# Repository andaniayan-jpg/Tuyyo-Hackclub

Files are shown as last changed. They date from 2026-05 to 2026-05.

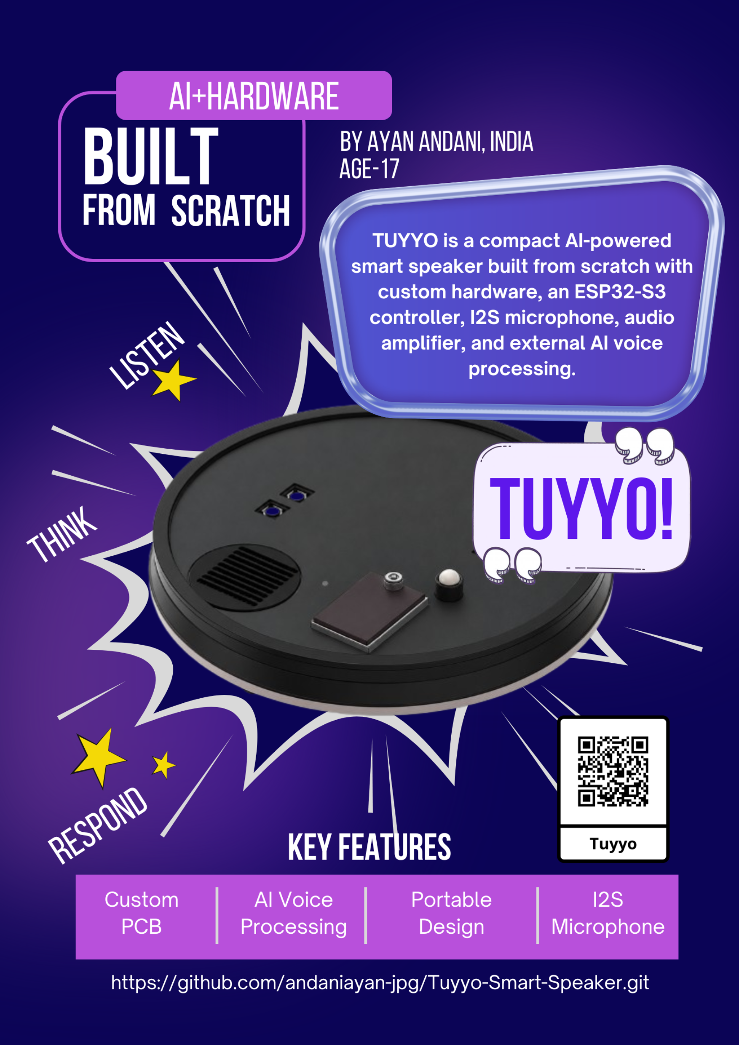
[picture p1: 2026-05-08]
ZINE PAGE .png

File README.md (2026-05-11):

# Tuyyo-Smart-Speaker

**TUYO is a compact, AI-powered voice assistant speaker that was designed and built completely from scratch. It combines custom embedded hardware with modern AI to create a portable assistant that can listen, process speech, and respond in real time.**

imresizer-trical p (1)

## Build Instructions

1. Download or clone this repository.
2. Open the KiCad project from the `PCB/` folder.
3. Review the schematic and PCB layout.
4. Generate or use the included Gerber files for PCB manufacturing.
5. Order the components listed in `BOM.csv`.
6. Assemble the PCB by soldering the ESP32-S3, microphone, amplifier, USB-C, charger, regulator, resistors, capacitors, LED, buttons, and connectors.
7. Place the assembled PCB inside the 3D printed enclosure.
8. Upload the firmware from `Firmware/tuyo_firmware.ino`.
9. Connect the external AI processing system for speech-to-text, AI response generation, and text-to-speech.
10. Power the device using USB-C or a LiPo battery.

## PCB and Schematic

The PCB was designed in KiCad. The `PCB/` folder includes the schematic, PCB layout, and manufacturing files.

## Firmware and AI Integration

The ESP32-S3 firmware initializes Wi-Fi, the I2S microphone, I2S amplifier, buttons, and status output. The ESP32 does not run the full AI model locally. It captures audio and is intended to send it to an external AI system, which handles speech-to-text, response generation, and text-to-speech playback.

# How to use it
-Power the device using a LiPo battery or USB-C connection.

-Ensure the system handling AI processing is connected.

-Speak clearly into the microphone.

-The device captures and processes your voice.

-The AI generates a response.

-The response is played through the speaker.

The interaction is designed to feel natural, similar to existing voice assistants.
# Components used
1. ESP32-WROOM-32 (Main Cintroller)
   -This is the brain of Tuyyo
   - Processes the input from the microphone
   - Sends data to the AI system
   - Receives responsee
   - Controls audio output with amplifier.
   - Handles system Logic and connects all other components.

  2. ICS-43434 I2S Microphone
  - This is a digital microphone used to capture voice output.
  - Convertes sound to digital signals.
  - Sends audio data to ESP32 using I2S protocol
  - Provides clear and noise-resistant audio input.

 3. MAX98357A I2S Audio Amplifier.
    - Recives data from ESP32.
    - Coverts to analog signal.
    - Enables clear audio output.
4. Speaker
   - Converts electrical signals into sound
   - Plays AI-generated responses
  
5. TP4056
   - Charges the battery from Usb-c port.

6. LiPO battery
   - Provides portable power
   - Replaceble
7. AMS1117-3.3 Voltage regulator
   - Converts 5V to 3.3V
   - Supplies power to ESP32 and other components that require 3.3V.
8. CH340C USB to UART.
   - Converts USB signal.
   - Helps in programming the ESP32.
9. USB-C RECEPTABLE
   - Provides 5v power to the system.
   - Allows connection to computer and charger.
10. APA-106-F5
11. FerriteBead
12. Resistors and Capacitors.

    

   # This project was created to explore the connection between hardware engineering and artificial intelligence.
   Rather than relying on existing smart speaker platforms, the goal was to understand and rebuild the entire system from the ground up. That meant designing the PCB, choosing the right components, managing power delivery, and integrating AI-based voice interaction into a working physical product.

   # What makes TUYO unique
-Fully custom-designed PCB

-Integration of AI with embedded systems

-Compact and portable design

-Clear separation of input, processing, and output

-Built from scratch as a complete system





Visit this BOM file for component list- "https://github.com/andaniayan-jpg/Tuyyo-Hackclub/blob/12cad96ed76dfa4e5342a210ed5bca2d6a44b040/pcb/Tuyyo%20all%20the%20gerbers.zip"

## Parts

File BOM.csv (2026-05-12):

Reference | Qty | Component | Value/Part | Footprint | Source | Link | Notes
R1,R6 | 2 | Resistor | 5.1k? | Resistor_SMD:R_0805_2012Metric | LCSC | https://www.lcsc.com/product-detail/C269748.html | USB-C CC pull-down resistors; PCB part list reference R1,R6
C1,C2,C3,C4,C5,C6,C7,C8 | 8 | Capacitor | 0.1µF / 100nF | Capacitor_SMD:C_0805_2012Metric | LCSC | https://www.lcsc.com/product-detail/C38141.html | Decoupling capacitors; PCB part list reference C1-C8
R2,R3 | 2 | Resistor | 10k? | Resistor_SMD:R_0805_2012Metric | LCSC | https://www.lcsc.com/product-detail/C115309.html | Pull-up / configuration resistors; PCB part list reference R2,R3
R5 | 1 | Resistor | 330k? | Resistor_SMD:R_0805_2012Metric | LCSC | https://www.lcsc.com/product-detail/C2479639.html | PCB resistor; PCB part list reference R5
SW1,SW2,SW3 | 3 | Push Button | 6x6mm tactile push button | Button_Switch_THT:SW_PUSH_6mm_H4.3mm | Robu | https://robu.in/product/6x6x5-tactile-push-button-switch | User control buttons; PCB part list reference SW1-SW3
MK1 | 1 | I2S MEMS Microphone | ICS-43434 | Sensor_Audio:Knowles_LGA-5_3.5x2.65mm | Adafruit | https://www.adafruit.com/product/6049 | I2S microphone for voice input; PCB part list reference MK1
LS1 | 1 | Speaker Connector | 1.00mm 1x02 vertical pin header | Connector_PinHeader_1.00mm:PinHeader_1x02_P1.00mm_Vertical | KiCad footprint reference | https://kicad.github.io/footprints/Connector_PinHeader_1.00mm.html | PCB connector for external speaker; PCB part list reference LS1
U6 | 1 | I2S Audio Amplifier IC | MAX98357A | Package_DFN_QFN:TQFN-16-1EP_3x3mm_P0.5mm_EP1.23x1.23mm | LCSC | https://www.lcsc.com/product-detail/C910544.html | I2S speaker amplifier; PCB part list reference U6
R4 | 1 | Resistor | 1.2k? | Resistor_SMD:R_0805_2012Metric | Quartz Components | https://quartzcomponents.com/products/1-2k-ohm-1k2-5-smd-resistor-0805-pack-of-20-pieces | PCB resistor; PCB part list reference R4
FB1 | 1 | Ferrite Bead | 0805 ferrite bead 600Ω 100MHz | Resistor_SMD:R_0805_2012Metric | Fair-Rite | https://fair-rite.com/product/chip-beads-2508056017y2/ | Power filtering ferrite bead; PCB part list reference FB1
U4 | 1 | USB-to-Serial IC | CH340C | Package_SO:SOIC-16_3.9x9.9mm_P1.27mm | Quartz Components | https://quartzcomponents.com/products/ch340c-usb-to-serial-ttl-converter-ic-smd-package | USB-to-UART programming interface; PCB part list reference U4
BT1 | 1 | Battery Connector | 1.00mm 1x02 vertical pin header | Connector_PinHeader_1.00mm:PinHeader_1x02_P1.00mm_Vertical | KiCad footprint reference | https://kicad.github.io/footprints/Connector_PinHeader_1.00mm.html | PCB connector for battery input; PCB part list reference BT1
U3 | 1 | Li-ion Charger IC | TP4056-42-ESOP8 | Package_SO:SOIC-8-1EP_3.9x4.9mm_P1.27mm_EP2.41x3.3mm_ThermalVias | LCSC | https://www.lcsc.com/product-detail/C16581.html | Single-cell Li-ion/LiPo charger IC; PCB part list reference U3
J1 | 1 | USB-C Receptacle | USB_C_Receptacle_USB2.0_14P | Connector_USB:USB_C_Receptacle_HCTL_HC-TYPE-C-16P-01A | LCSC | https://www.lcsc.com/product-detail/C2894897.html | USB-C power/data connector; PCB part list reference J1
D1 | 1 | Addressable RGB LED | APA-106-F5 | LED_THT:LED_D5.0mm-4_RGB | SparkFun datasheet | https://cdn.sparkfun.com/datasheets/Components/LED/COM-12877.pdf | Status RGB LED; PCB part list reference D1
U5 | 1 | Voltage Regulator | AMS1117-3.3 | Package_TO_SOT_SMD:SOT-223-3_TabPin2 | LCSC | https://www.lcsc.com/product-detail/C6186.html | 3.3V voltage regulator; PCB part list reference U5
U1 | 1 | MCU Module | ESP32-S3-WROOM-1 | RF_Module:ESP32-S3-WROOM-1 | Espressif | https://www.espressif.com/en/module/esp32-s3-wroom-1-en | Main microcontroller module; PCB part list reference U1
PCB1 | 1 | Custom PCB | TUYO Smart Speaker PCB | Gerber-manufactured PCB | JLCPCB / GitHub Gerbers | https://github.com/andaniayan-jpg/Tuyyo-Hackclub/blob/12cad96ed76dfa4e5342a210ed5bca2d6a44b040/pcb/Tuyyo%20all%20the%20gerbers.zip | Main printed circuit board manufactured from Gerber files; required physical PCB item
BAT1 | 1 | Battery | 3.7V 500mAh LiPo rechargeable battery | External part | Probots | https://probots.co.in/3-7v-500mah-lipo-battery-502248-open-ended.html | External battery connected to BT1
SPK1 | 1 | Speaker | 4? 3W mini speaker | External part | Roboman | https://roboman.in/product/4-ohm-3-6-watt-speaker-42mm-diameter/ | External speaker connected to LS1
CASE1 | 1 | Enclosure | Custom 3D printed TUYO enclosure | 3D printed part | Self-printed | 3D PRINTER
CABLE1 | 1 | USB-C Cable | USB-C data/power cable | External cable | Amazon / local supplier | https://www.amazon.in/Portronics-Charging-Aluminium-compatible-Smartphones/dp/B0CR6JQT6F | Used for power/programming
MECH1 | 1 | Mounting hardware | M2.5 hex screws | Mechanical hardware | Amazon India | https://www.amazon.in/303pcs-Screws-Hexagon-6mm-30mm-Screwdrivers/dp/B071F5HSJV

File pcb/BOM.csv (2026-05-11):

Item | Quantity | Purpose | Source | Link
3.7V Li-ion | 1 | Battery for the model | ELECTRONICSPICES | https://electronicspices.com/product/500mah-3-7v-single-cell-rechargeable-lipo-battery-hcy-602030
ESP32-S3-WROOM-1 | 1 | MCU | DigiKey | https://www.digikey.in/en/products/detail/espressif-systems/ESP32-S3-WROOM-1-N8R8/15295891?gclsrc=aw.ds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
(Microphone)ICS-43434 I2S MEMS microphone | 1 | Audio | DigiKey | https://www.digikey.in/en/products/detail/adafruit-industries-llc/6049/25589349
MAX98357A I2S audio amplifier IC | 1 | Audio output | DigiKey | https://www.digikey.in/en/products/detail/analog-devices-inc-maxim-integrated/MAX98357AETE-T/4936122
TP4056-42-ESOP8 Li-ion charger IC | 1 | Charging | EVELETA | https://evelta.com/tp4056x-42-esop8-lithium-ion-battery-management-1a-ic-sop-8-ep/?sku=129-TP4056X-42-ESOP8
CH340C USB to serial IC SOIC-16 | 1 | USB to UART | SUNROM | https://www.sunrom.com/p/ch340g-soic16-usb-to-serial-ttl-uart-ic
AMS1117-3.3 SOT-223 voltage regulator | 1 | Voltage regulate | ROBU.IN | https://robu.in/product/ams1117-3-3v-1a-sot-223-voltage-regulator-ic-pack-of-5-ics?gad_campaignid=17427802703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
USB-C receptacle | 1 | USB C PORT | DigiKey | https://www.digikey.in/en/products/detail/gct/USB4930-00-A/28722818
Connector 1x02 | 2 | Connector | 3dfindit | https://www.3dfindit.com/en/digitaltwin/pinheader1x02p100mmvertical
Speaker | 1 | Speaker | ELECTRONICSPICES | https://electronicspices.com/product/2-inch-4%CF%89-ohm-5w-metal-body-power-audio-woofer-speaker-round-shape
LED | 1 | RGB LED | ELECTRONIFY INDIA | https://www.electronifyindia.com/products/2-pin-rgb-led-5mm-auto-flashing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
Type 1 resistor | 2 | Resistors | Quartz component | https://quartzcomponents.com/products/4-3k-ohm-4k3-1-smd-resistor-0805-pack-of-20-pieces-copy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
Type 2 resistors | 2 | Resistors | Quartz component | https://quartzcomponents.com/products/10k-ohm-103-5-smd-resistor-0805-pack-of-20-pieces?variant=43451349729514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
Type 3 resistors | 1 | Resistors | Quartz component | https://quartzcomponents.com/products/1-2k-ohm-1k2-5-smd-resistor-0805-pack-of-20-pieces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
Type 4 resistrors | 1 | Resistors | LCSC | https://www.lcsc.com/product-detail/C101661.html
Capacitors | 8 | Capacitors | Quartz component | https://quartzcomponents.com/products/100nf-0-1uf-104-50v-1206-smd-capacitor-pack-of-10-pieces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
Push buttons | 3 | Controlls | Amazon | https://www.amazon.in/6X6X4-3mm-MICRO-SWITCH-Tactile-Button/dp/B0CK651LD1?th=1
Ferrite bead | 1 | Ferrite bead | DigiKey | https://www.digikey.in/en/products/detail/fair-rite-products-corp/2508056017Y2/8594310
PCB | 1 | PCB | JLCPCB | https://github.com/andaniayan-jpg/Tuyyo-Hackclub/blob/12cad96ed76dfa4e5342a210ed5bca2d6a44b040/pcb/Tuyyo%20all%20the%20gerbers.zip

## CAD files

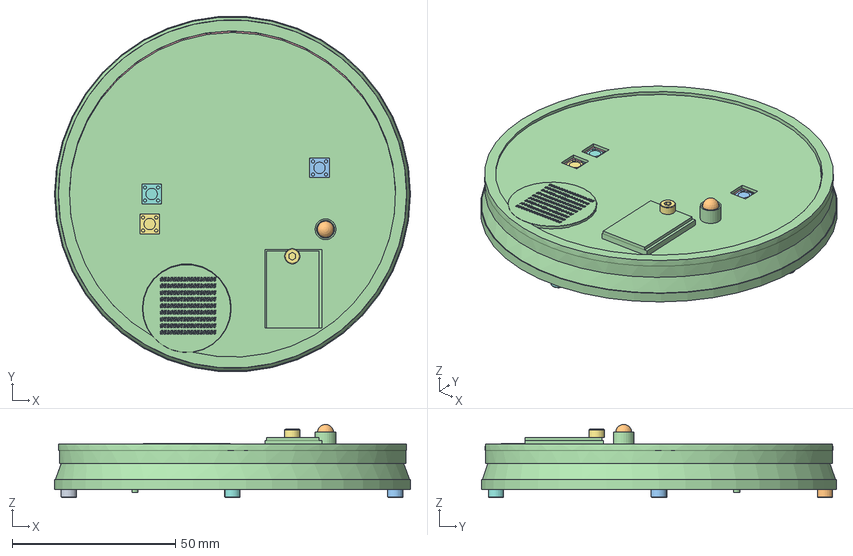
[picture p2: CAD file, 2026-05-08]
cad_assembly/Tuyyo.FCStd
109.0 x 108.7 x 22.4 mm
R_0805_2012Metric
C_0805_2012Metric
SW_PUSH_6mm_H4.3mm
ICS-43434--3DModel-STEP-418109
PinHeader_1x02_P1.00mm_Vertical
QFN-16 (3x3) Part1
QFN-16 (3x3) Part2
QFN-16 (3x3) Part001
QFN-16 (3x3) Part002
QFN-16 (3x3) Part003
QFN-16 (3x3) Part004
QFN-16 (3x3) Part005
QFN-16 (3x3) Part006
QFN-16 (3x3) Part007
QFN-16 (3x3) Part008
QFN-16 (3x3) Part009
QFN-16 (3x3) Part010
QFN-16 (3x3) Part011
QFN-16 (3x3) Part012
QFN-16 (3x3) Part013
QFN-16 (3x3) Part014
QFN-16 (3x3) Part015
SOIC-16_3.9x9.9mm_P1.27mm
TP4056-42-ESOP8_TPW
TypC_port
LED_D5.0mm-4_RGB
SOT-223
ESP32-S3-WROOM-1
Tuyyo_PCB
C_0805_2012Metric001
R_0805_2012Metric001
R_0805_2012Metric002
C_0805_2012Metric002
C_0805_2012Metric003
C_0805_2012Metric004
R_0805_2012Metric003
C_0805_2012Metric005
C_0805_2012Metric006
SW_PUSH_6mm_H4.3mm001
SW_PUSH_6mm_H4.3mm002
R_0805_2012Metric004
R_0805_2012Metric005
PinHeader_1x02_P1.00mm_Vertical001
R_0805_2012Metric006
C_0805_2012Metric007
Speaker 20 mm
M2.5 Hex Screw v2
M2.5 Hex Screw v001
M2.5 Hex Screw v002
M2.5 Hex Screw v003
M2.5 Hex Screw v004

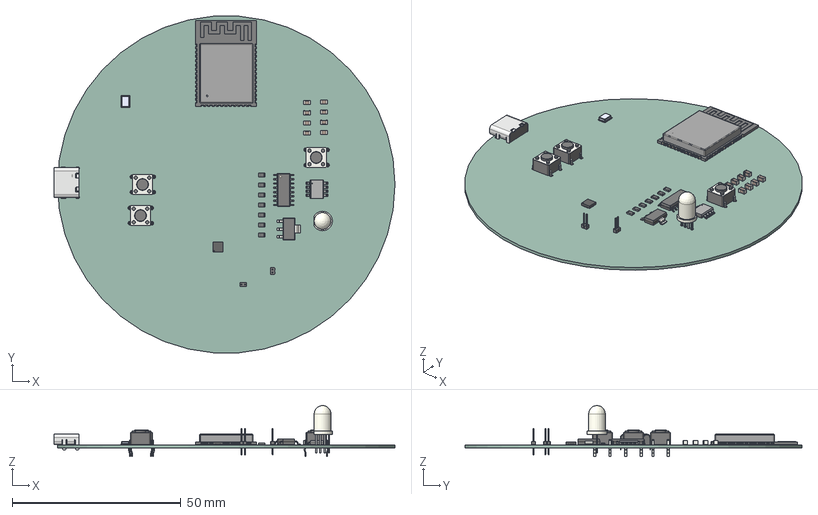
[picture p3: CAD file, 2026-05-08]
pcb/Tuyyo.step
100.9 x 99.6 x 15.1 mm
R_0805_2012Metric x 7
C_0805_2012Metric x 8
SW_PUSH_6mm_H4.3mm x 3
ICS-43434--3DModel-STEP-418109
PinHeader_1x02_P1.00mm_Vertical x 2
QFN-16 (3x3) Part1
QFN-16 (3x3) Part2 x 16
SOIC-16_3.9x9.9mm_P1.27mm
TP4056-42-ESOP8_TPW
TypC_port
LED_D5.0mm-4_RGB
SOT-223
ESP32-S3-WROOM-1
Tuyyo_PCB

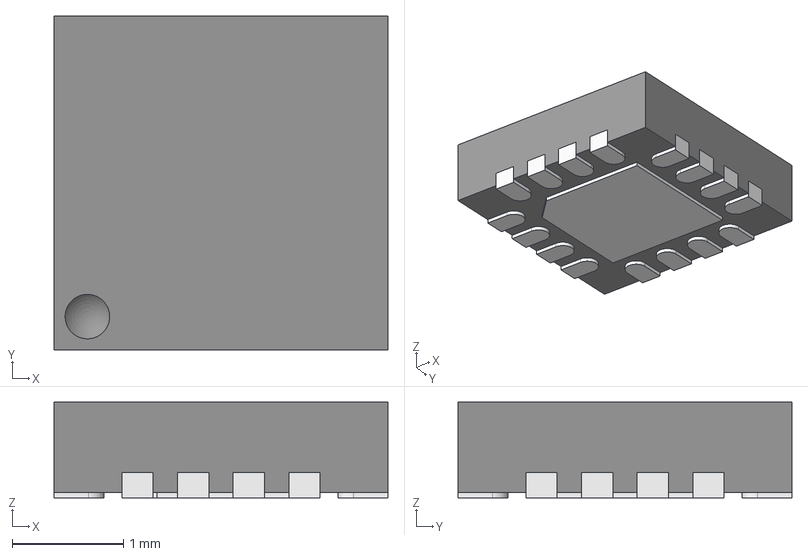
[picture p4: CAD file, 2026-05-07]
cad_assembly/QFN-16 (3x3).step
3.00 x 3.00 x 0.86 mm

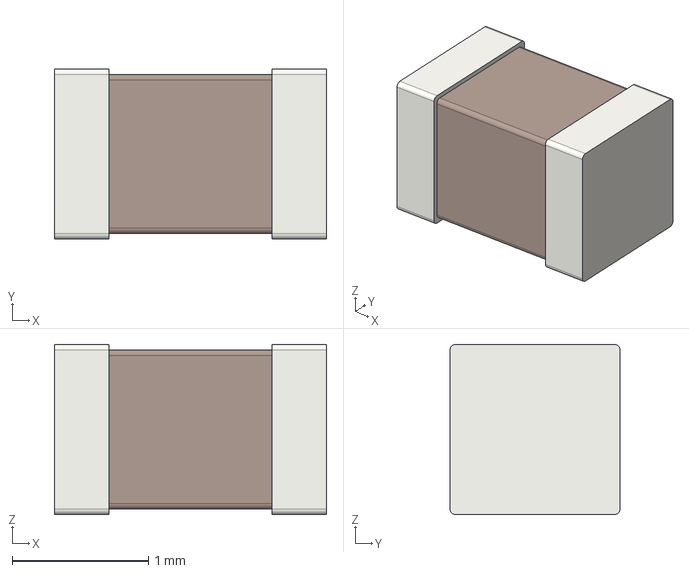
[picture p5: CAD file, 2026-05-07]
cad_assembly/C_0805_2012Metric CAPACITOR.step
2.00 x 1.25 x 1.25 mm

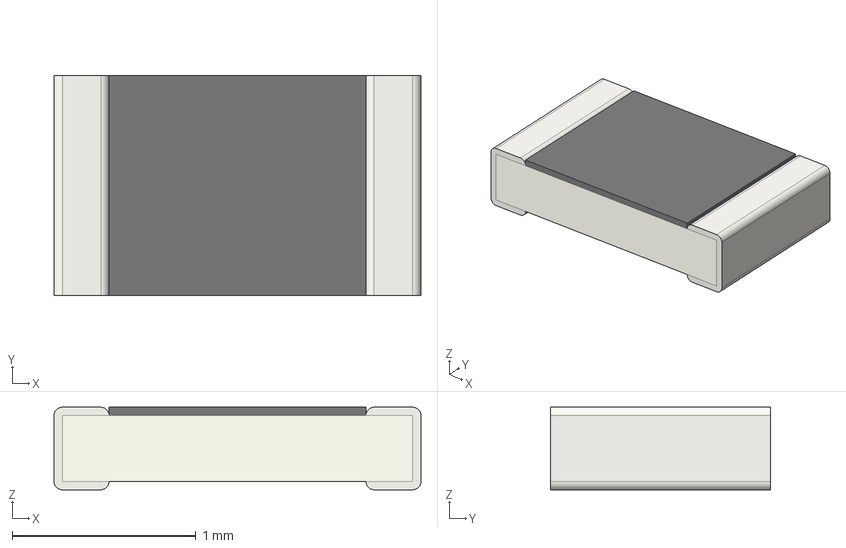
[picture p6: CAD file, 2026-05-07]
cad_assembly/R_0805_2012Metric.step
2.00 x 1.20 x 0.45 mm

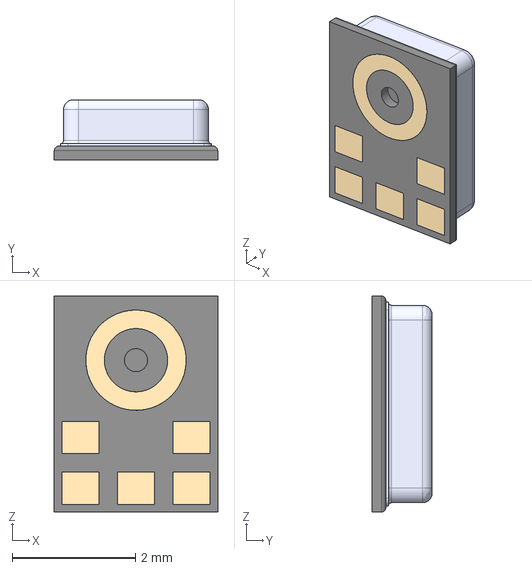
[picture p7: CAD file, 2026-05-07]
cad_assembly/ICS-43434--3DModel-STEP-418109.step
2.65 x 0.98 x 3.50 mm

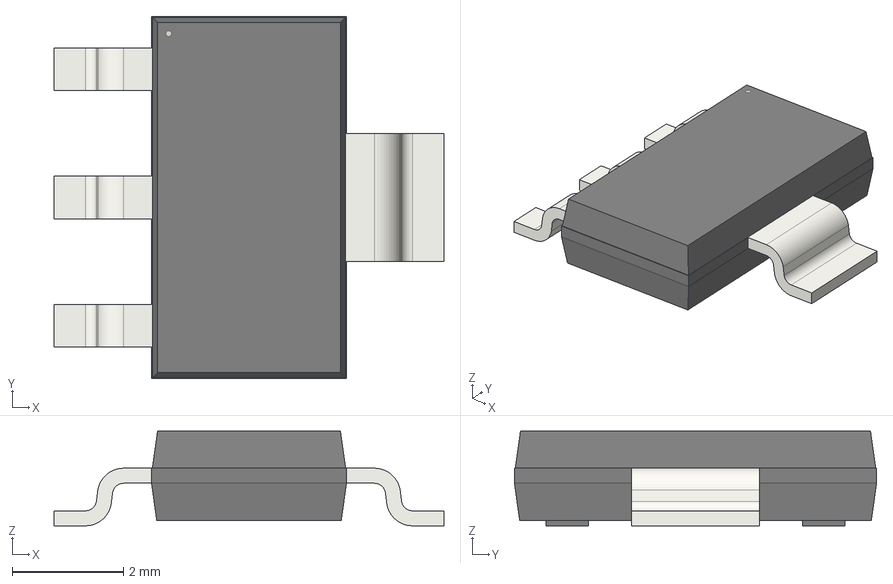
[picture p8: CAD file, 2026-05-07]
cad_assembly/SOT-223.step
7.00 x 6.50 x 1.70 mm

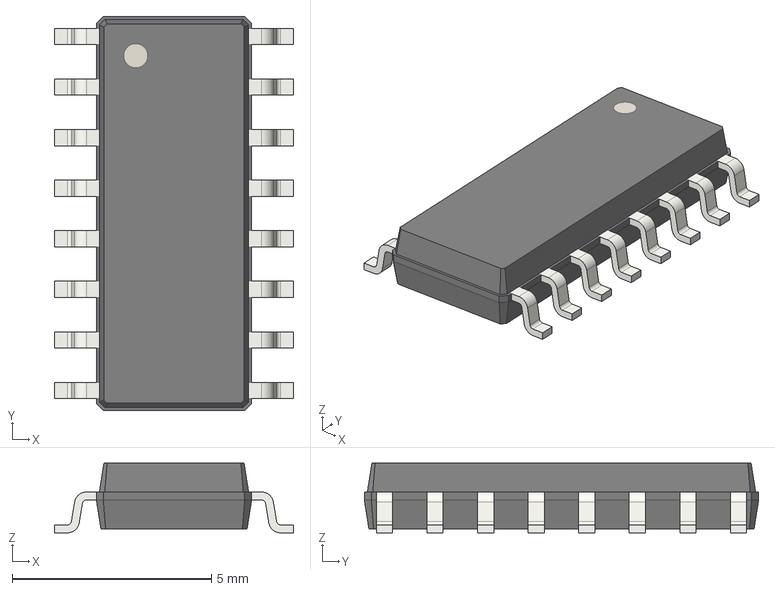
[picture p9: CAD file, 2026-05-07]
cad_assembly/SOIC-16_3.9x9.9mm_P1.27mm.step
6.00 x 9.90 x 1.75 mm

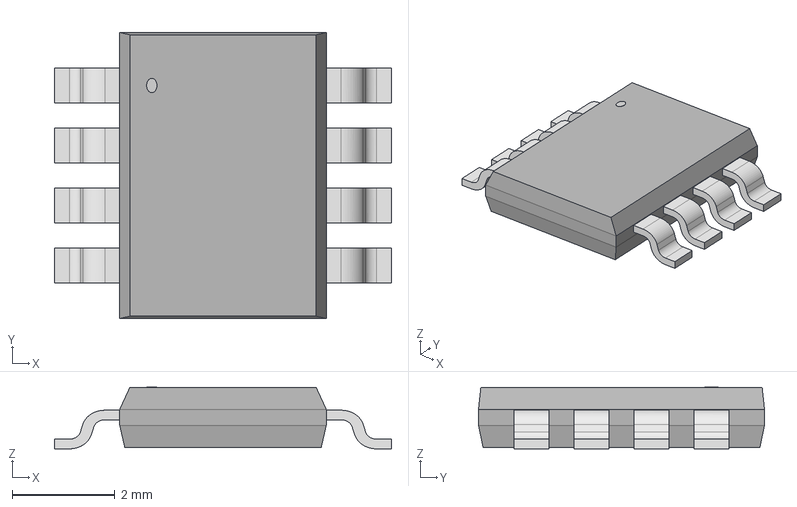
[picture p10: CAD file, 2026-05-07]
cad_assembly/TP4056-42-ESOP8_TPW.step
6.57 x 5.58 x 1.20 mm

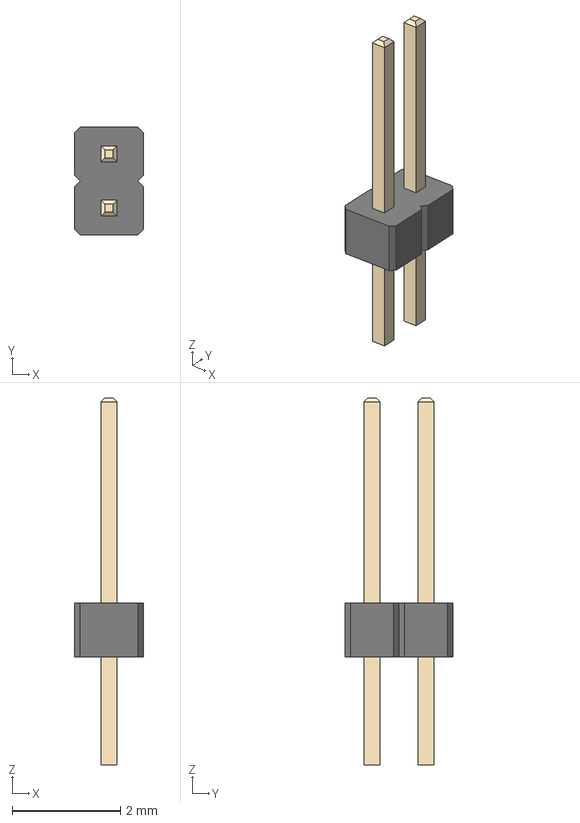
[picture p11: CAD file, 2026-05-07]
cad_assembly/PinHeader_1x02_P1.00mm_Vertical for battery .step
1.27 x 2.00 x 6.79 mm

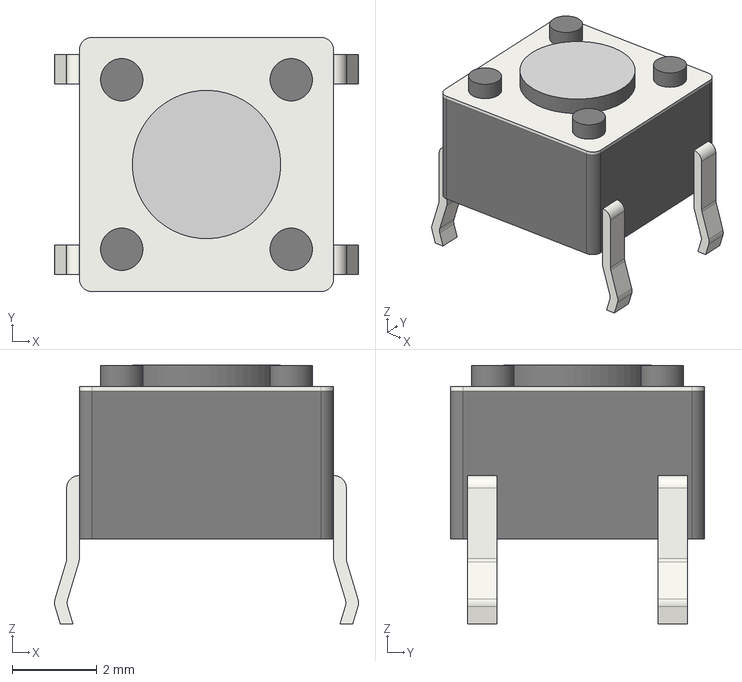
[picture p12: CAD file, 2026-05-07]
cad_assembly/SW_PUSH_6mm_H4.3mm.step
7.17 x 6.00 x 6.10 mm

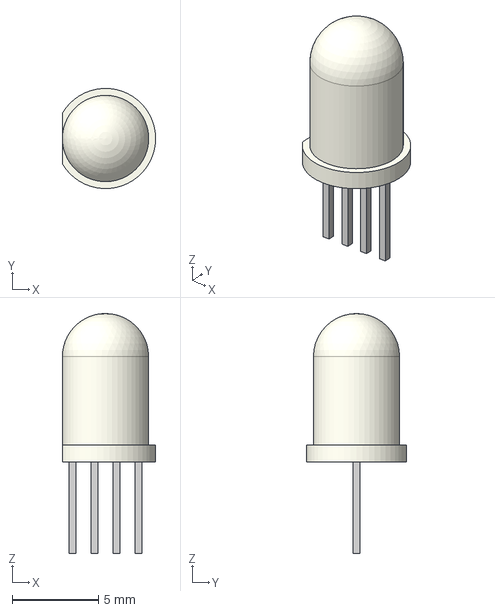
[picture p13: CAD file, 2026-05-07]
cad_assembly/LED_D5.0mm-4_RGB.step
5.40 x 5.79 x 13.9 mm

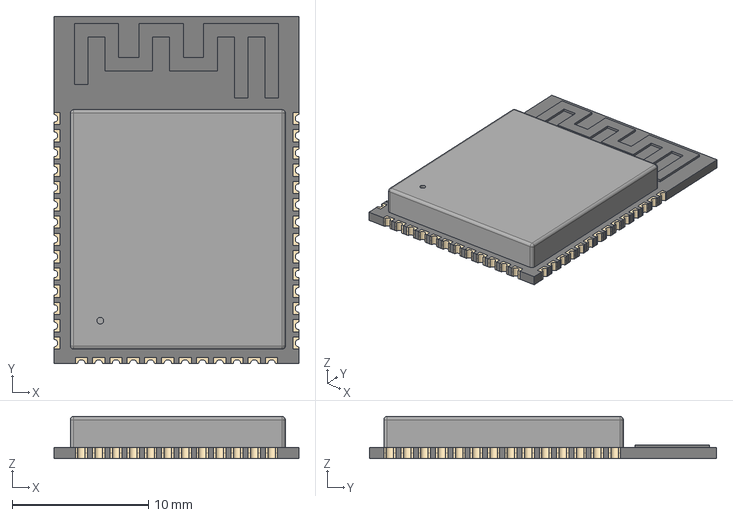
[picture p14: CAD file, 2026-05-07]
cad_assembly/ESP32-S3-WROOM-1.step
18.0 x 25.5 x 3.10 mm

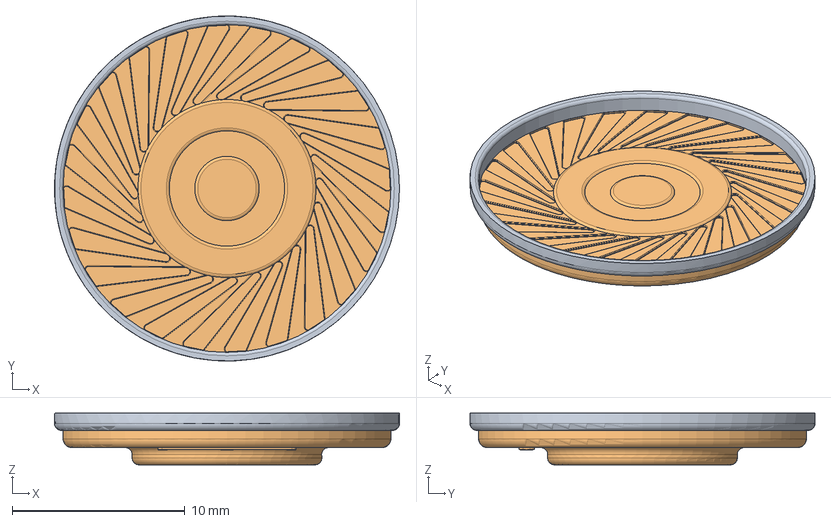
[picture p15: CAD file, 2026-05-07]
cad_assembly/Speaker 20 mm.step
20.0 x 20.0 x 3.00 mm

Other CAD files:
cad_assembly/PinHeader_1x02_P1.00mm_Vertical.step
cad_assembly/M2.5 Hex Screw v2.step

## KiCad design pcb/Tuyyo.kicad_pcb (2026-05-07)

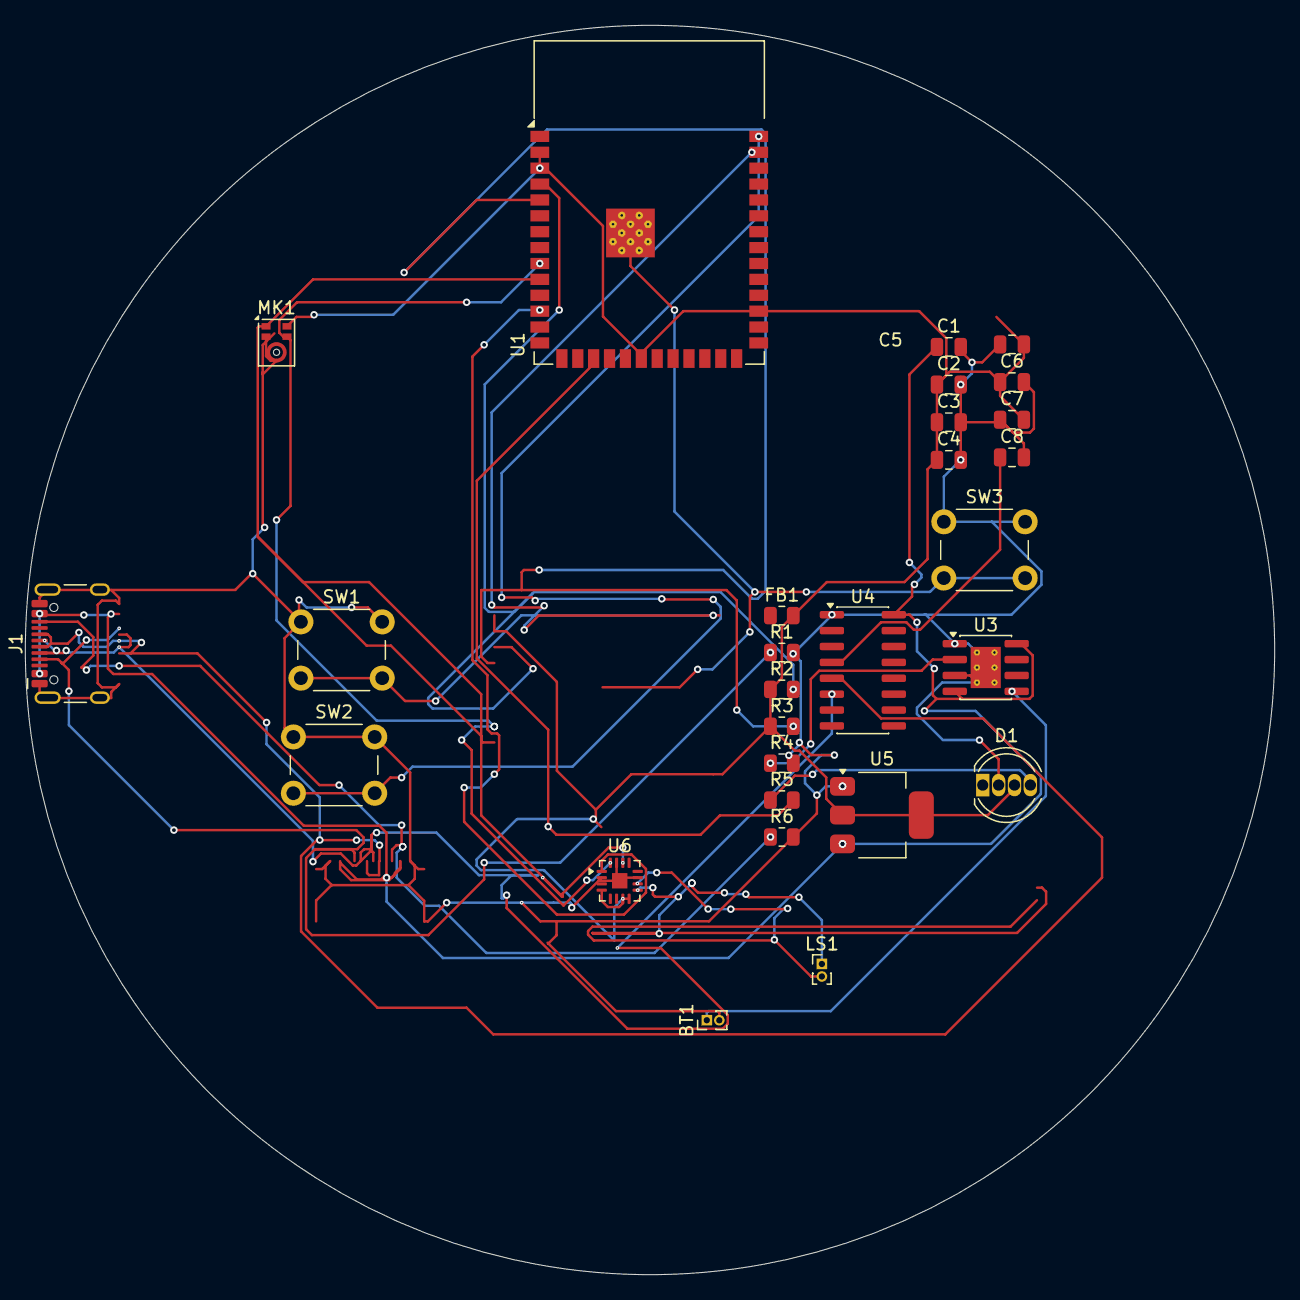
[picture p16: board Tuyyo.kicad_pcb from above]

Board: 2 copper layers, 99.9 x 99.9 mm, 28 parts (0 on the bottom side), 22 nets.

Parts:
BT1: Battery; PinHeader_1x02_P1.00mm_Vertical
C1, C2, C3, C4, C5, C6, C7, C8: 0.1 µF; C_0805_2012Metric
D1: APA-106-F5; LED_D5.0mm-4_RGB
FB1: FerriteBead; R_0805_2012Metric
J1: USB_C_Receptacle_USB2.0_14P; USB_C_Receptacle_HCTL_HC-TYPE-C-16P-01A
LS1: Speaker; PinHeader_1x02_P1.00mm_Vertical
MK1: ICS-43434; Knowles_LGA-5_3.5x2.65mm
R1, R6: 5.1kΩ; R_0805_2012Metric
R2, R3: 10kΩ; R_0805_2012Metric
R4: 1.2kΩ; R_0805_2012Metric
R5: 330kΩ; R_0805_2012Metric
SW1, SW2, SW3: SW_Push; SW_PUSH_6mm_H4.3mm
U1: ESP32-S3; ESP32-S3-WROOM-1
U3: TP4056-42-ESOP8; SOIC-8-1EP_3.9x4.9mm_P1.27mm_EP2.41x3.3mm_ThermalVias
U4: CH340C; SOIC-16_3.9x9.9mm_P1.27mm
U5: AMS1117-3.3; SOT-223-3_TabPin2
U6: MAX98357A; TQFN-16-1EP_3x3mm_P0.5mm_EP1.23x1.23mm

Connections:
+3.3V: C2.1, C3.1, C4.1, C5.2, C6.1, C7.2, D1.3 (VDD), FB1.2, MK1.5 (VDD), R2.1, R3.1, U1.2 (VDD3P3), U1.3 (VDD3P3), U1.20 (VDD3P3_RTC), U1.29 (VDD_SPI), U5.2 (VO), U6.4 (~SD_MODE), U6.7 (VDD), U6.8 (VDD)
/5V RAIL: C1.1, J1.A4 (VBUS), J1.A9 (VBUS), J1.B4 (VBUS), J1.B9 (VBUS), U3.4 (V_{CC}), U3.8 (CE), U4.16 (VCC), U5.3 (VI)
/B+: BT1.1 (+), U3.5 (BAT)
/CC1: J1.A5 (CC1), R1.1
/CC2: J1.B5 (CC2), R6.1
/D+: J1.A6 (D+), J1.B6 (D+), U4.5 (UD+)
/D-: J1.A7 (D-), J1.B7 (D-), U4.6 (UD-)
/EN: R2.2, U1.4 (CHIP_PU)
/GPIO4: MK1.4 (SCK), U1.9 (GPIO4), U6.16 (BCLK)
/GPIO5: MK1.1 (WS), U1.10 (GPIO5), U6.14 (LRCLK)
/GPIO7: U1.12 (GPIO7), U6.1 (DIN)
/GPIO12: R5.2, U1.17 (GPIO12)
/GPIO34: SW1.2, U1.39 (GPIO34)
/GPIO35: SW2.2, U1.40 (GPIO35)
/GPIO36: SW3.2, U1.41 (GPIO36)
/IO0: R3.2, U1.5 (GPIO0)
/SPEAKER+: LS1.1, U6.9 (OUTP)
/SPEAKER_: LS1.2, U6.10 (OUTN)
GND: BT1.2 (-), C1.2, C2.2, C3.2, C4.2, C5.1, C6.2, C7.1, C8.2, D1.2 (GND), J1.A1 (GND), J1.A12 (GND), J1.B1 (GND), J1.B12 (GND), J1.S1 (SHIELD), MK1.2 (LR), MK1.3 (GND), R1.2, R4.2, R6.2, SW1.1, SW2.1, SW3.1, U3.1 (TEMP), U3.3 (GND), U3.9 (EPAD), U4.1 (GND), U5.1 (GND), U6.2 (GAIN_SLOT), U6.3 (GND), U6.11 (GND), U6.15 (GND), U6.17 (PAD)
unnamed: D1.4 (DI), R5.1
unnamed: R4.1, U3.2 (PROG)
unnamed: C8.1, U4.4 (V3)

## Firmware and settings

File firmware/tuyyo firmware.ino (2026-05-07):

#include <WiFi.h>
#include "driver/i2s.h"
#include <math.h>

const char* WIFI_SSID = "wifi name";
const char* WIFI_PASSWORD = "wifi password";

const char* AI_SERVER_IP = "192.168.1.10";
const int AI_SERVER_PORT = 5000;

// APA-106 / status LED data pin
#define STATUS_LED_PIN 12

// Push buttons from schematic
#define BUTTON_1 34
#define BUTTON_2 35
#define BUTTON_3 36

// Shared I2S clock pins from schematic
#define I2S_BCLK 4
#define I2S_LRCLK 5

// ICS-43434 microphone data pin
#define MIC_DATA_IN 6

// MAX98357A amplifier data pin
#define SPEAKER_DATA_OUT 7

#define SAMPLE_RATE 16000
#define BUFFER_SIZE 512

#define I2S_PORT I2S_NUM_0

void blinkStatusPin(int times, int delayMs) {
  for (int i = 0; i < times; i++) {
    digitalWrite(STATUS_LED_PIN, HIGH);
    delay(delayMs);
    digitalWrite(STATUS_LED_PIN, LOW);
    delay(delayMs);
  }
}

void connectWiFi() {
  Serial.println();
  Serial.println("Connecting to Wi-Fi...");

  WiFi.mode(WIFI_STA);
  WiFi.begin(WIFI_SSID, WIFI_PASSWORD);

  int attempt = 0;

  while (WiFi.status() != WL_CONNECTED && attempt < 30) {
    delay(500);
    Serial.print(".");
    attempt++;
  }

  Serial.println();

  if (WiFi.status() == WL_CONNECTED) {
    Serial.println("Wi-Fi connected.");
    Serial.print("IP address: ");
    Serial.println(WiFi.localIP());
    blinkStatusPin(3, 150);
  } else {
    Serial.println("Wi-Fi not connected.");
    Serial.println("Continuing in offline hardware test mode.");
    blinkStatusPin(5, 100);
  }
}

void setupI2SAudio() {
  i2s_config_t i2sConfig = {};
  i2sConfig.mode = (i2s_mode_t)(I2S_MODE_MASTER | I2S_MODE_TX | I2S_MODE_RX);
  i2sConfig.sample_rate = SAMPLE_RATE;
  i2sConfig.bits_per_sample = I2S_BITS_PER_SAMPLE_32BIT;
  i2sConfig.channel_format = I2S_CHANNEL_FMT_ONLY_LEFT;
  i2sConfig.communication_format = I2S_COMM_FORMAT_I2S;
  i2sConfig.intr_alloc_flags = ESP_INTR_FLAG_LEVEL1;
  i2sConfig.dma_buf_count = 4;
  i2sConfig.dma_buf_len = 256;
  i2sConfig.use_apll = false;
  i2sConfig.tx_desc_auto_clear = true;
  i2sConfig.fixed_mclk = 0;

  i2s_pin_config_t i2sPins = {};
  i2sPins.bck_io_num = I2S_BCLK;
  i2sPins.ws_io_num = I2S_LRCLK;
  i2sPins.data_out_num = SPEAKER_DATA_OUT;
  i2sPins.data_in_num = MIC_DATA_IN;

  esp_err_t installResult = i2s_driver_install(I2S_PORT, &i2sConfig, 0, NULL);

  if (installResult != ESP_OK) {
    Serial.print("I2S driver install failed. Error code: ");
    Serial.println(installResult);
    return;
  }

  esp_err_t pinResult = i2s_set_pin(I2S_PORT, &i2sPins);

  if (pinResult != ESP_OK) {
    Serial.print("I2S pin setup failed. Error code: ");
    Serial.println(pinResult);
    return;
  }

  i2s_zero_dma_buffer(I2S_PORT);

  Serial.println("I2S audio initialized.");
  Serial.println("Microphone: ICS-43434");
  Serial.println("Amplifier: MAX98357A");
}

void playTestTone() {
  Serial.println("Playing speaker test tone...");

  int frequency = 440;
  int durationMs = 700;
  int totalSamples = (SAMPLE_RATE * durationMs) / 1000;

  size_t bytesWritten;

  for (int i = 0; i < totalSamples; i++) {
    float t = (float)i / SAMPLE_RATE;
    int32_t sample = (int32_t)(60000000 * sin(2.0 * PI * frequency * t));

    i2s_write(I2S_PORT, &sample, sizeof(sample), &bytesWritten, portMAX_DELAY);
  }

  Serial.println("Speaker test tone finished.");
}

int readMicLevel() {
  int32_t buffer[BUFFER_SIZE];
  size_t bytesRead = 0;

  esp_err_t result = i2s_read(
    I2S_PORT,
    buffer,
    sizeof(buffer),
    &bytesRead,
    100 / portTICK_PERIOD_MS
  );

  if (result != ESP_OK || bytesRead == 0) {
    return 0;
  }

  int samplesRead = bytesRead / sizeof(int32_t);
  long total = 0;

  for (int i = 0; i < samplesRead; i++) {
    int32_t sample = buffer[i] >> 14;
    total += abs(sample);
  }

  return total / samplesRead;
}

void readButtons() {
  int button1State = digitalRead(BUTTON_1);
  int button2State = digitalRead(BUTTON_2);
  int button3State = digitalRead(BUTTON_3);

  if (button1State == LOW) {
    Serial.println("Button 1 pressed");
  }

  if (button2State == LOW) {
    Serial.println("Button 2 pressed");
  }

  if (button3State == LOW) {
    Serial.println("Button 3 pressed");
  }
}

void sendAudioToAIServer() {
  Serial.println("AI server communication is planned for the next firmware version.");
}

void setup() {
  Serial.begin(115200);
  delay(1000);

  pinMode(STATUS_LED_PIN, OUTPUT);
  digitalWrite(STATUS_LED_PIN, LOW);

  pinMode(BUTTON_1, INPUT);
  pinMode(BUTTON_2, INPUT);
  pinMode(BUTTON_3, INPUT);

  Serial.println();
  Serial.println("Starting TUYO Smart Speaker firmware...");
  Serial.println("Firmware version: 0.1");
  Serial.println("Board: Custom ESP32-WROOM-32 TUYO PCB");

  Serial.println();
  Serial.println("Pin map:");
  Serial.println("I2S BCLK  -> GPIO4");
  Serial.println("I2S LRCLK -> GPIO5");
  Serial.println("Mic SD    -> GPIO6");
  Serial.println("Speaker DIN -> GPIO7");
  Serial.println("LED/Data  -> GPIO12");
  Serial.println("Buttons   -> GPIO34, GPIO35, GPIO36");

  blinkStatusPin(2, 200);

  connectWiFi();
  setupI2SAudio();
  playTestTone();

  Serial.println();
  Serial.println("Setup complete.");
  Serial.println("Reading microphone levels...");
}

void loop() {
  int micLevel = readMicLevel();

  Serial.print("Mic level: ");
  Serial.println(micLevel);

  readButtons();

  if (micLevel > 500) {
    digitalWrite(STATUS_LED_PIN, HIGH);
  } else {
    digitalWrite(STATUS_LED_PIN, LOW);
  }

  delay(200);
}

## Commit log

2026-05-11 Rename BOM FINAL.csv to BOM.csv
    [BOM.csv]
2026-05-12 Rename TUYYYOOOOO BOMM.csv to BOM.csv
    [BOM.csv]
